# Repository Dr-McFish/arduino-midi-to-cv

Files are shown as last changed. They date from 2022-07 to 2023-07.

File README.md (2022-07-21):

# arduino-midi-to-cv
This arduino project accsepts MIDI input and translates it into various control voltages for a synthesiser.

## Features

 * 0 to 5 volt v/octave output, with 0V corresponding to MIDI note 36 (C2).
 * Monophonic, highest note priority
 * Gate Output
 
### Work in progress (planned features):

 * Pitch bend support (on the v/octave output)
 * Mod wheel output
 * Velocity output
 * OLED screen with options menu
 * Note priority option
 * Gate retrigger/legato option

## Installation requirements

 * if one desires this to work over usb, then flashing the [mocoLUFA](https://github.com/kuwatay/mocolufa) firware to the arduino is required. I personaly found this [tutorial](https://youtu.be/-bCz2I9SMAA) helpfull. Otherwise use a 5 pin MIDI connector circuit(not shown).
 * Upload with arduino IDE or comand line utility

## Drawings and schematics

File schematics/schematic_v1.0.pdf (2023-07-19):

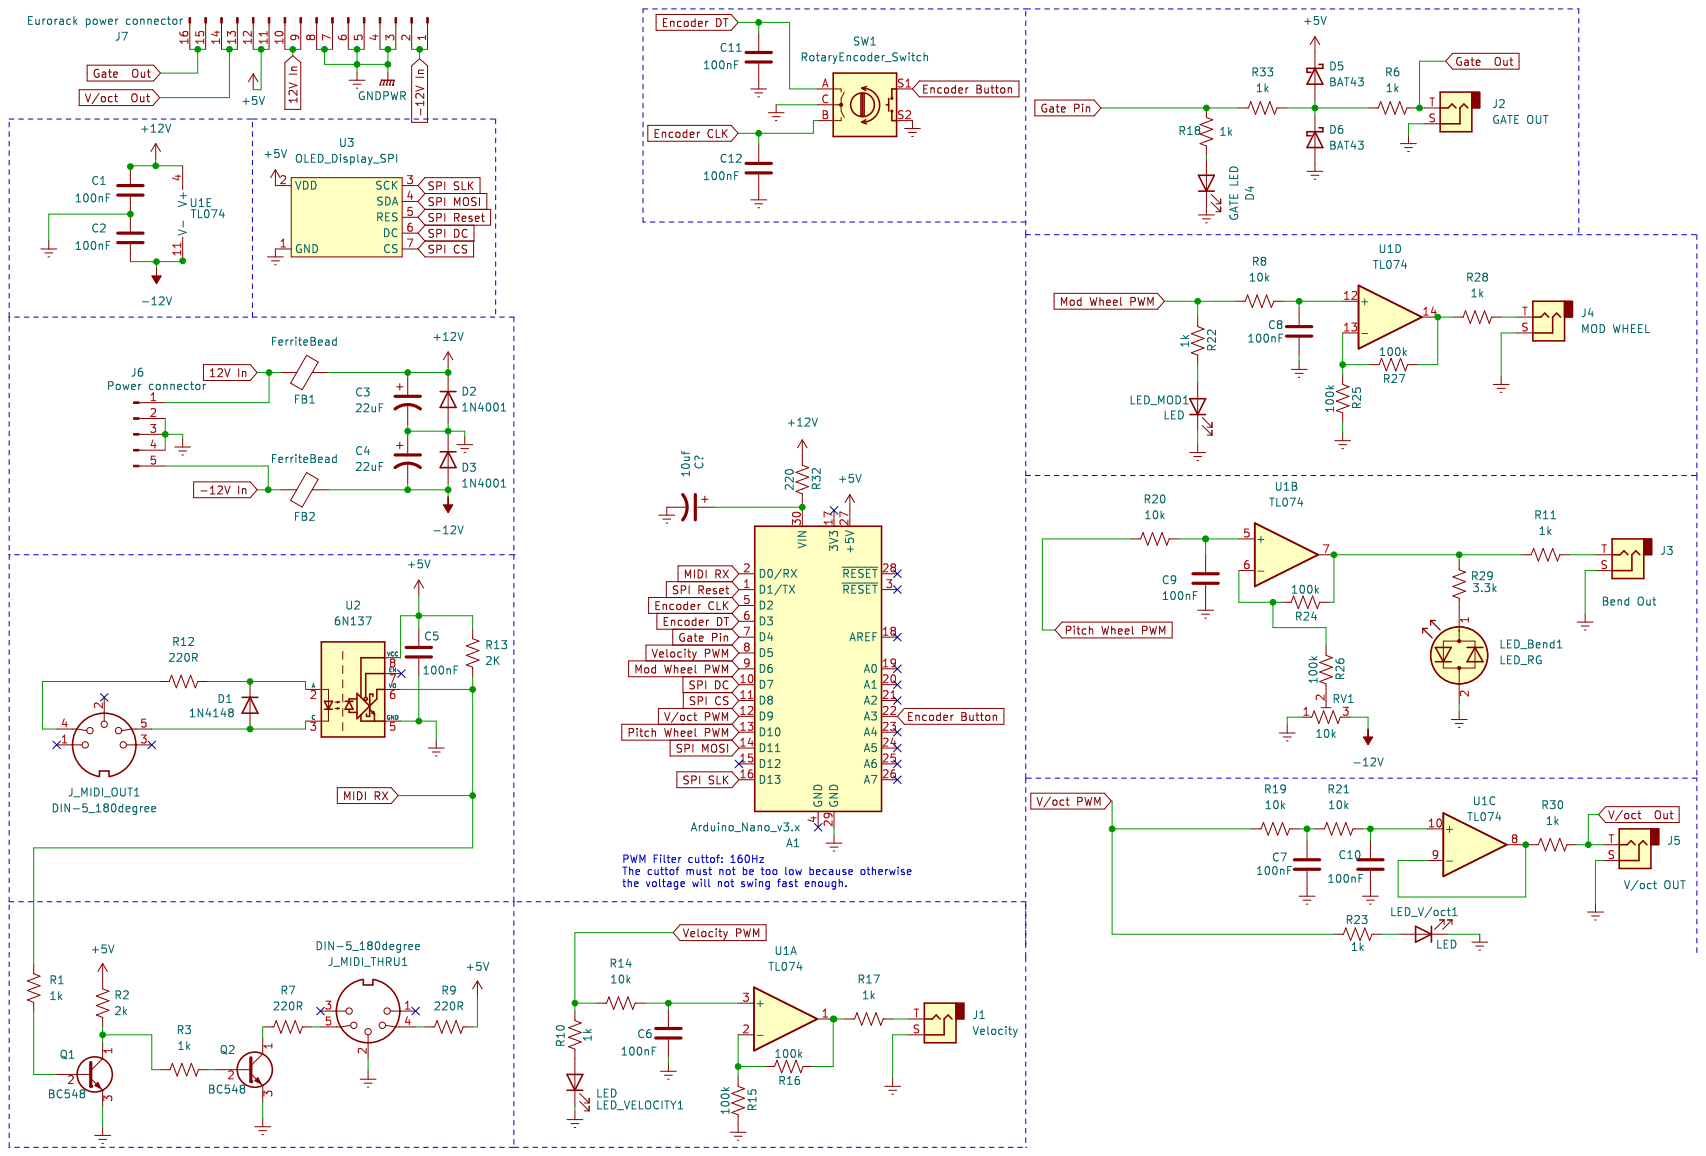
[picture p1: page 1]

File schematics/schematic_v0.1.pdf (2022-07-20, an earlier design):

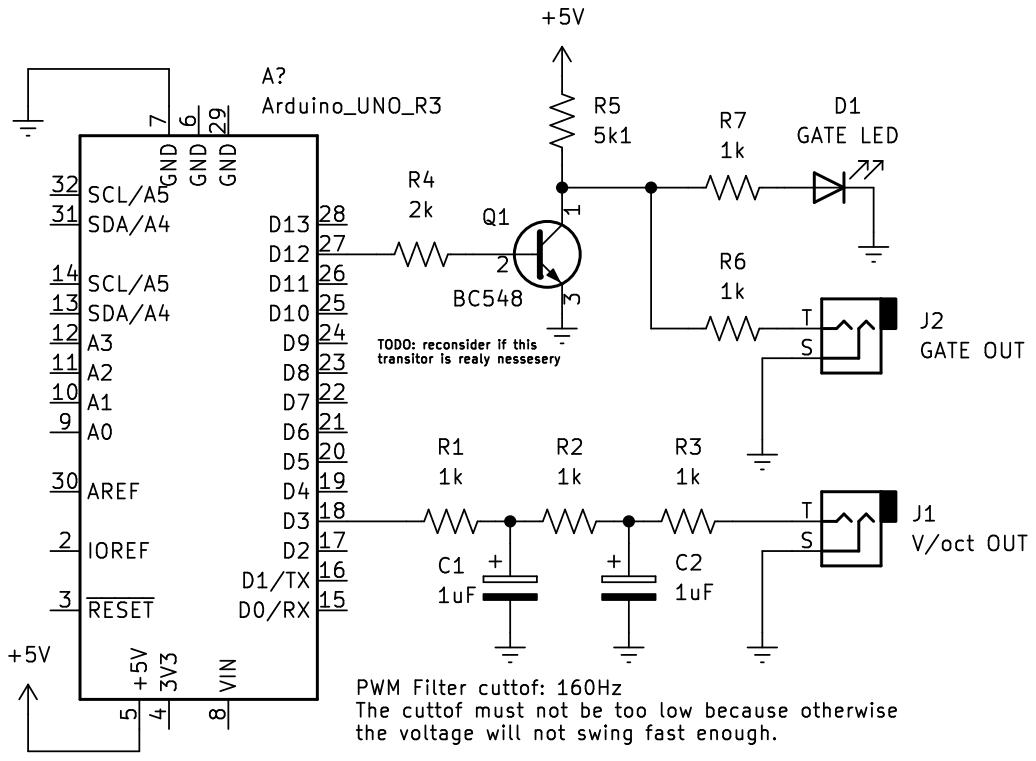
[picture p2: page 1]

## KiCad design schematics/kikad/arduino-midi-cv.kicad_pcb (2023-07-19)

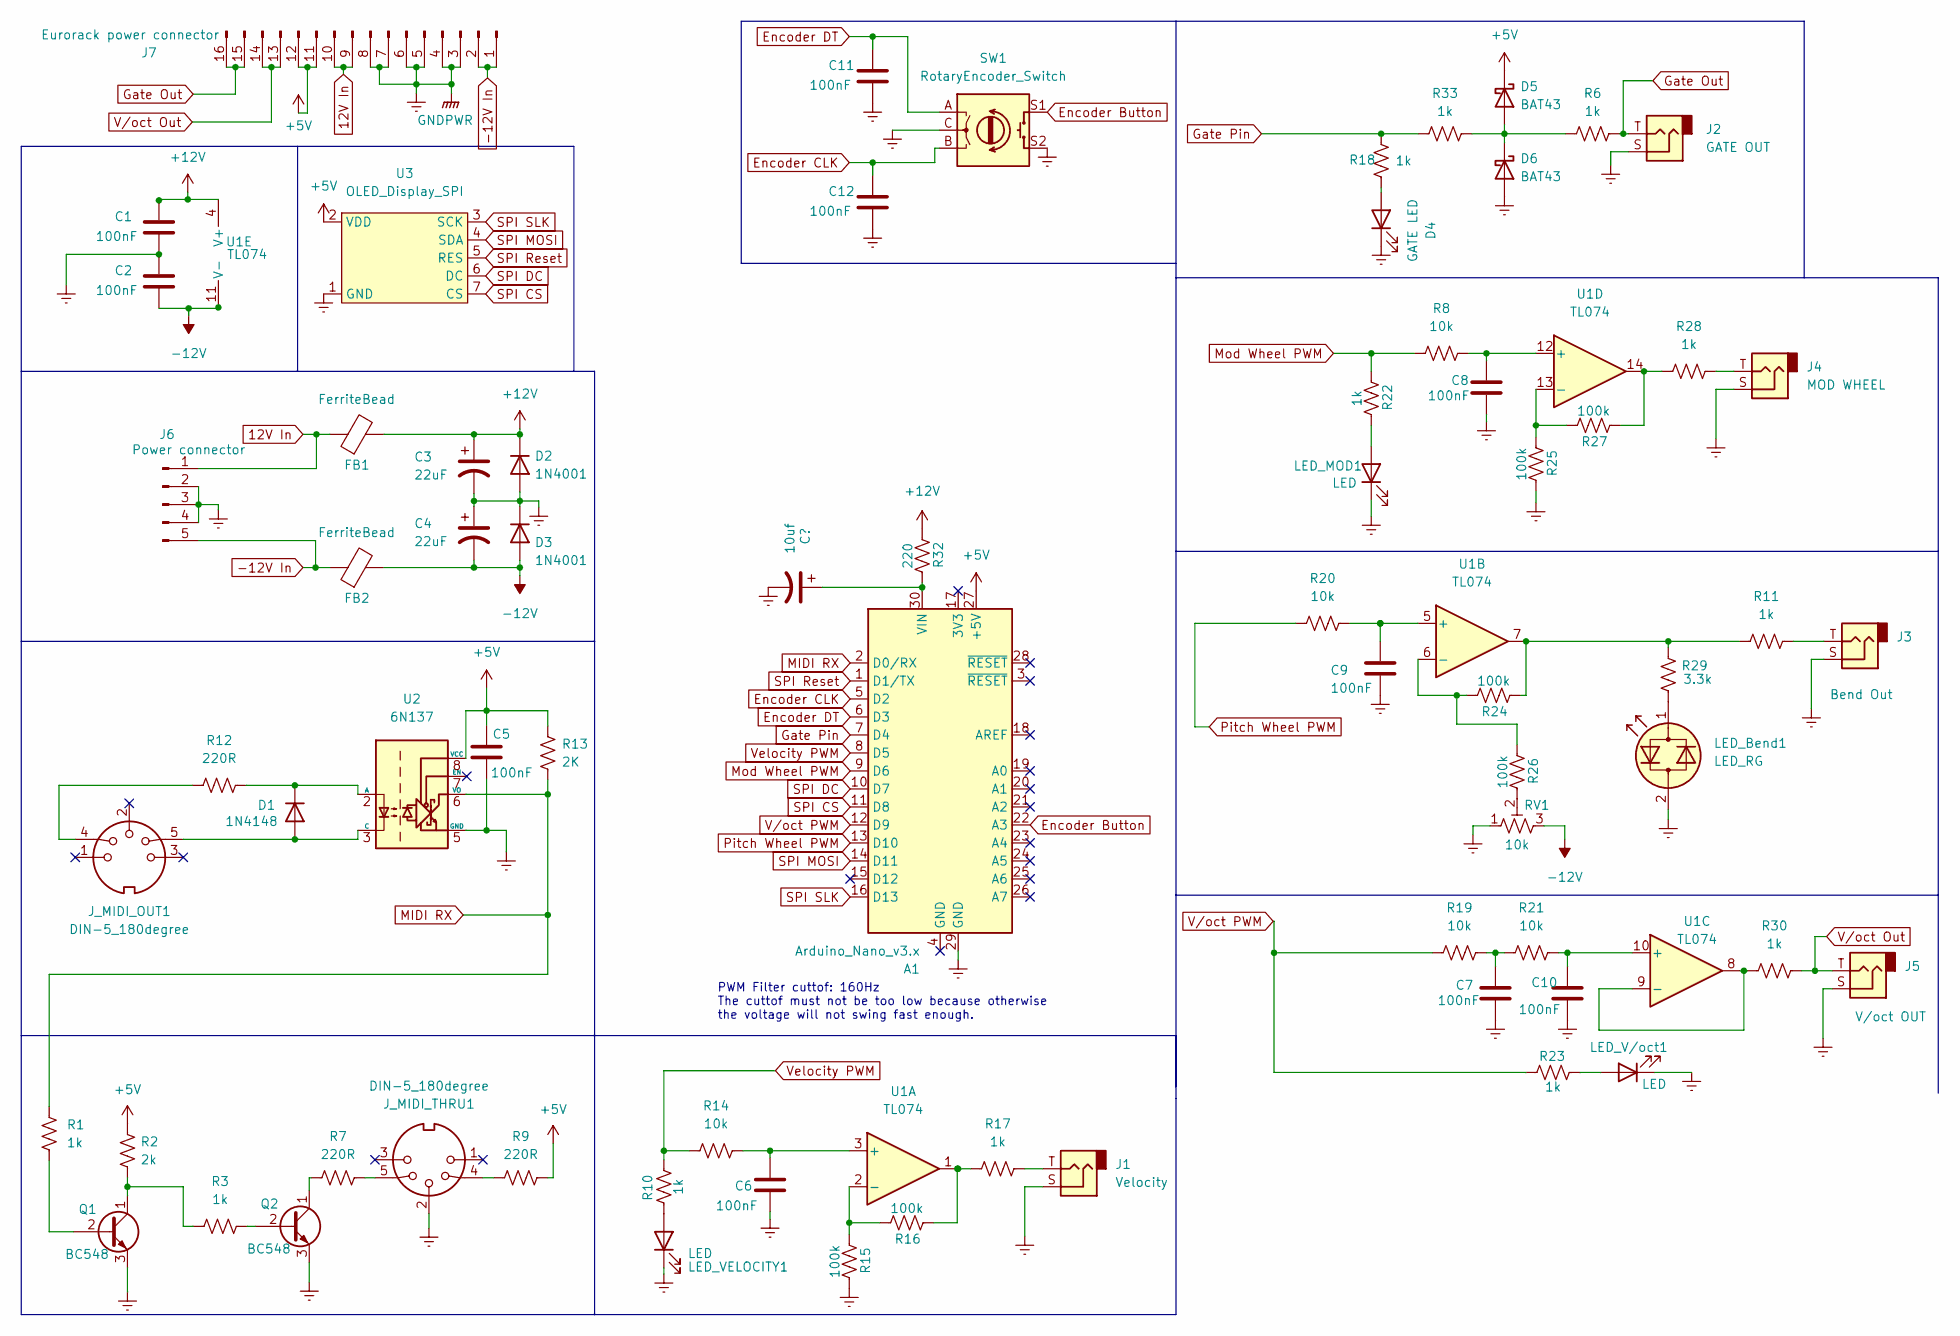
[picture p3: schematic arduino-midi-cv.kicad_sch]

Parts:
A1: Arduino_Nano_v3.x; Arduino_Nano
C1, C2, C5, C6, C7, C8, C9, C10, C11, C12: 100nF; C_Disc_D3.0mm_W1.6mm_P2.50mm
C3, C4: 22uF; CP_Radial_D5.0mm_P2.50mm
D1: 1N4148; D_DO-35_SOD27_P2.54mm_Vertical_AnodeUp
D2, D3: 1N4001; D_DO-41_SOD81_P12.70mm_Horizontal
D4: GATE LED; LED_D5.0mm
D5, D6: BAT43; D_DO-35_SOD27_P7.62mm_Horizontal
FB1, FB2: FerriteBead; R_Axial_DIN0207_L6.3mm_D2.5mm_P10.16mm_Horizontal
J1: Velocity; Jack breakcout cables
J2: GATE OUT; Jack breakcout cables
J3: Bend Out; Jack breakcout cables
J4: MOD WHEEL; Jack breakcout cables
J5: V/oct OUT; Jack breakcout cables
J6: Power connector; JST_XH_B5B-XH-A_1x05_P2.50mm_Vertical
J7: Eurorack power connector; IDC-Header_2x08_P2.54mm_Vertical
J_MIDI_OUT1: DIN-5_180degree; SIP-2
J_MIDI_THRU1: DIN-5_180degree; SIP-2
LED_Bend1: LED_RG; LED_D5.0mm
LED_MOD1: LED; LED_D5.0mm
LED_V/oct1: LED; LED_D5.0mm
LED_VELOCITY1: LED; LED_D5.0mm
Q1, Q2: BC548; TO-92_Inline
R1, R3, R6, R10, R11, R17, R18, R22, R23, R28, R30, R33: 1k; R_Axial_DIN0207_L6.3mm_D2.5mm_P10.16mm_Horizontal
R2: 2k; R_Axial_DIN0207_L6.3mm_D2.5mm_P10.16mm_Horizontal
R7, R9: 220R; R_Axial_DIN0207_L6.3mm_D2.5mm_P10.16mm_Horizontal
R8, R14, R19, R20, R21: 10k; R_Axial_DIN0207_L6.3mm_D2.5mm_P10.16mm_Horizontal
R12: 220R; R_Axial_DIN0207_L6.3mm_D2.5mm_P2.54mm_Vertical
R13: 2K; R_Axial_DIN0207_L6.3mm_D2.5mm_P7.62mm_Horizontal
R15, R26: 100k; R_Axial_DIN0207_L6.3mm_D2.5mm_P10.16mm_Horizontal
R16, R24, R25, R27: 100k; R_Axial_DIN0207_L6.3mm_D2.5mm_P2.54mm_Vertical
R29: 3.3k; R_Axial_DIN0207_L6.3mm_D2.5mm_P10.16mm_Horizontal
R32: 220; R_0805_2012Metric_Pad1.20x1.40mm_HandSolder
RV1: 10k; Potentiometer_Bourns_3296W_Vertical
SW1: RotaryEncoder_Switch; RotaryEncoder_Alps_EC11E-Switch_Vertical_H20mm
U1: TL074; DIP-14_W7.62mm_Socket
U2: 6N137; DIP-8_W7.62mm
U3: OLED_Display_SPI; SPI Oled dislay SH1106

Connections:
12V In: FB1.1, J6.1, J7.9, J7.10
+5V: A1.27 (+5V), C5.1, D5.1 (K), J7.11, J7.12, R2.2, R9.1, R13.2, U2.8 (VCC), U3.2 (VDD)
+12V: C1.1, C3.1, D2.1 (K), FB1.2, R32.2, U1.4 (V+)
-12V: C2.2, C4.2, D3.2 (A), FB2.2, RV1.3, U1.11 (V-)
-12V In: FB2.1, J6.5, J7.1, J7.2
Earth: A1.29 (GND), C1.2, C2.1, C3.2, C4.1, C5.2, C6.2, C7.2, C8.2, C9.2, C10.2, C11.2, C12.2, D2.2 (A), D3.1 (K), D4.1 (K), D6.2 (A), J1.S, J2.S, J3.S, J4.S, J5.S, J6.2, J6.3, J6.4, J7.3, J7.4, J7.5, J7.6, J7.7, J7.8, J_MIDI_THRU1.2, LED_Bend1.2 (AK), LED_MOD1.1 (K), LED_V/oct1.1 (K), LED_VELOCITY1.1 (K), Q1.3 (E), Q2.3 (E), R15.1, R25.1, RV1.1, SW1.C, SW1.S2, U2.5 (GND), U3.1 (GND)
Encoder Button: A1.22 (A3), SW1.S1
Encoder CLK: A1.5 (D2), C12.1, SW1.B
Encoder DT: A1.6 (D3), C11.1, SW1.A
Gate Out: J2.T, J7.15, J7.16, R6.2
Gate Pin: A1.7 (D4), R18.1, R33.1
MIDI RX: A1.2 (D0/RX), R1.2, R13.1, U2.6 (VO)
Mod Wheel PWM: A1.9 (D6), R8.1, R22.2
unnamed: A1.30 (VIN), R32.1
unnamed: C6.1, R14.2, U1.3 (+)
unnamed: C7.1, R19.2, R21.1
unnamed: C8.1, R8.2, U1.12 (+)
unnamed: C9.1, R20.2, U1.5 (+)
unnamed: C10.1, R21.2, U1.10 (+)
unnamed: D1.1 (K), R12.2, U2.2 (A)
unnamed: D1.2 (A), J_MIDI_OUT1.5, U2.3 (C)
unnamed: D4.2 (A), R18.2
unnamed: D5.2 (A), D6.1 (K), R6.1, R33.2
unnamed: J1.T, R17.2
unnamed: J3.T, R11.2
unnamed: J4.T, R28.2
unnamed: J_MIDI_OUT1.4, R12.1
unnamed: J_MIDI_THRU1.4, R9.2
unnamed: J_MIDI_THRU1.5, R7.1
unnamed: LED_Bend1.1 (KA), R29.2
unnamed: LED_MOD1.2 (A), R22.1
unnamed: LED_V/oct1.2 (A), R23.1
unnamed: LED_VELOCITY1.2 (A), R10.2
unnamed: Q1.1 (C), R2.1, R3.2
unnamed: Q1.2 (B), R1.1
unnamed: Q2.1 (C), R7.2
unnamed: Q2.2 (B), R3.1
unnamed: R11.1, R24.2, R29.1, U1.7
unnamed: R15.2, R16.1, U1.2 (-)
unnamed: R16.2, R17.1, U1.1
unnamed: R24.1, R26.2, U1.6 (-)
unnamed: R25.2, R27.1, U1.13 (-)
unnamed: R26.1, RV1.2
unnamed: R27.2, R28.1, U1.14
unnamed: R30.1, U1.8, U1.9 (-)
Pitch Wheel PWM: A1.13 (D10), R20.1
SPI CS: A1.11 (D8), U3.7 (CS)
SPI DC: A1.10 (D7), U3.6 (DC)
SPI MOSI: A1.14 (D11), U3.4 (SDA)
SPI Reset: A1.1 (D1/TX), U3.5 (RES)
SPI SLK: A1.16 (D13), U3.3 (SCK)
Velocity PWM: A1.8 (D5), R10.1, R14.1
V/oct Out: J5.T, J7.13, J7.14, R30.2
V/oct PWM: A1.12 (D9), R19.1, R23.2

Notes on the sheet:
PWM Filter cuttof: 160Hz The cuttof must not be too low because otherwise the voltage will not swing fast enough.

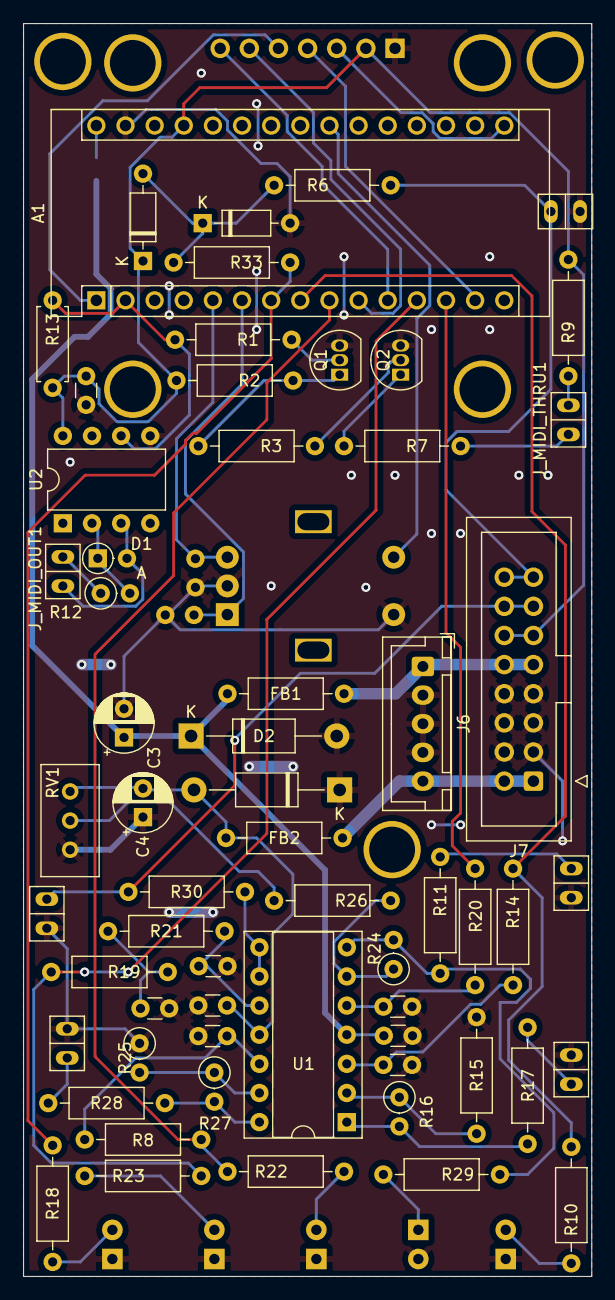
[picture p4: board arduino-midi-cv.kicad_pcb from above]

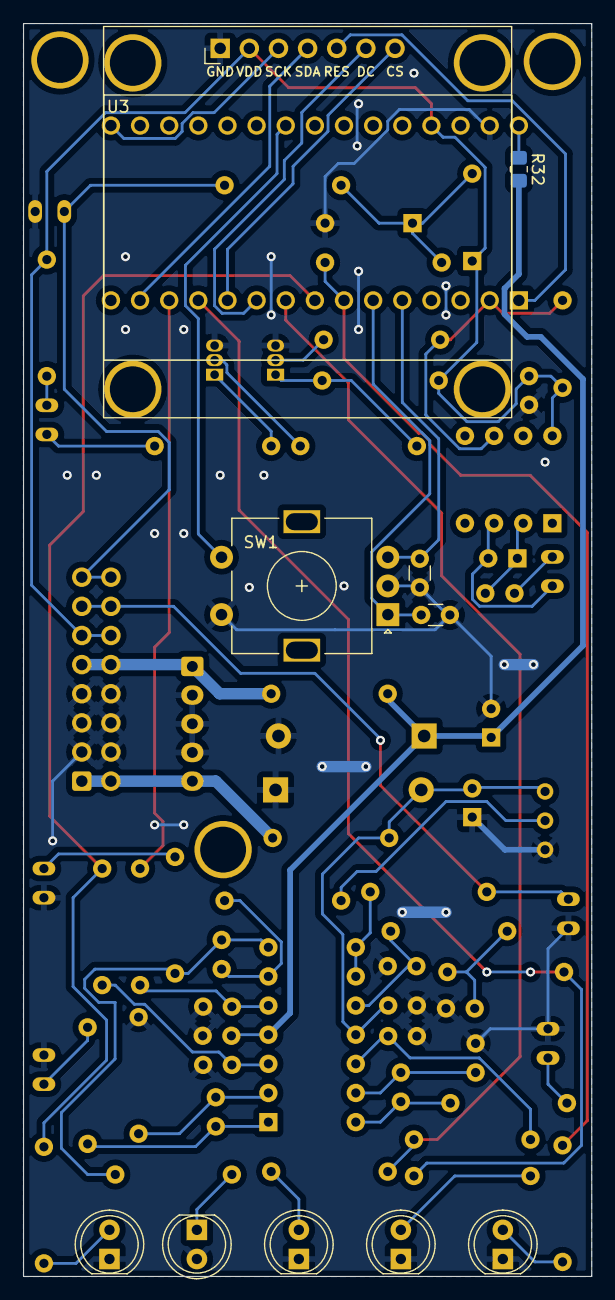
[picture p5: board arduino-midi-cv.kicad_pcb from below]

Board: 2 copper layers, 49.5 x 109.2 mm, 71 parts (10 on the bottom side), 54 nets.

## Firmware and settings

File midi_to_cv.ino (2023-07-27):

#include <MCP_DAC.h>
#include <MIDI.h>
#include <stdint.h>

#include "encoder.h"
#include "display.h"
#include "bool_array.hpp"
#include "settings.h"

constexpr int8_t MIN_NOTE =36; /*note C2*/
constexpr int8_t NUM_OCTAVES = 8;
typedef int note_number_t; /* 0 - 60; MIN_NOTE is 0 */

int pitchbend = 0;

BoolArray notes_on = BoolArray();
bool note_on_update = false;
MIDI_CREATE_DEFAULT_INSTANCE();

const int gate_pin = 4; // D4 -> pin PD4 on Atmega328p
const int gate_pin_bitmask = 4; // bit 4 on the `PORTD` register
const int enc_btn_pin = A3;
const int enc_btn_pin_bitmask = 3; //bit 3 on the `PORTC` register

int note_to_volt_per_oct_10bit(byte note);
note_number_t midinote_to_notenum(byte midi_note);

void HandleNoteOn(byte channel, byte pitch, byte velocity);
void HandleNoteOff(byte channel, byte pitch, byte velocity) ;
void HandleCC(byte channel, byte control_function, byte parameter);
void HandlePitchBend(byte channel, int bend);

inline void updateNoteAndGate();
inline void updateMenu();

MCP4922 MCP;  // HW SPI DAC
enum DAC_CHANNEL {
	CH_V_OCT = 0, //Channel A
	CH_PITCH_BEND = 1, //Channel B
};

struct settings_s settings = {{4, 12}, 0b00000100, 0, false};


void setup() 
{
	// ------------------------------------------------- MIDI -------------------------------------------------- 
	MIDI.begin(MIDI_CHANNEL_OMNI);
	MIDI.turnThruOff();
	//Serial.begin(9600);
	
	// As of the MIDI Library v3.1, the lib uses C style function 
	// pointers to create a callback system for handling input events. 
	MIDI.setHandleNoteOn(HandleNoteOn); 
	MIDI.setHandleControlChange(HandleCC);
	MIDI.setHandleNoteOff(HandleNoteOff);
	MIDI.setHandlePitchBend(HandlePitchBend);

	// ------------------------------------------------ display ------------------------------------------------
	display_setup();
	draw_text("hello");
	// ------------------------------------------------ encoder ------------------------------------------------ 
	setup_encoder();
	
	// -------------------------------------------------- DAC --------------------------------------------------
	// Todo: it may be fasater to use SPI library insted of this MCP library
	MCP.begin(A4);
	MCP.setGain(2);


	// ----------------------------------------------- Gate pin ------------------------------------------------  

	pinMode(gate_pin, OUTPUT);
	pinMode(A3, INPUT_PULLUP);


	// TODO : migrate mod and velocity to Timer 1(pins 9 and 10) for more resolution(and less scary high frequencies? I have no idea what I am doing)

	// ###################################### DEPRICATED! Replaced with DAC! ######################################

	// pinMode(9, OUTPUT); // Volt per octave
	// pinMode(10, OUTPUT); // Pitch Wheel raw
	// ------------------------------------------------ TIMER 1 ------------------------------------------------
	// //       Enable PWM out on pin D9(OC1A)    Enable PWM out on pin D10(OC1B)      Fast PWM 10bit mode
	// TCCR1A = _BV(COM1A1)                     | _BV(COM1B1)                        | _BV(WGM11) | _BV(WGM10); //WGM12
	// //        prescaler of 1, 15,6kHz
	// TCCR1B = _BV(CS10)                                                            | _BV(WGM12);
	// OCR1A = 0; // pin D9  pwm value (0-1023) (v/oct)
	// OCR1B = 0x01Ff; // pin D10 pwm value (0-1023) (pitchbend)
	write_bend(0);

	pinMode(6, OUTPUT); // Mod Wheel
	pinMode(5, OUTPUT); // Velocity
	// ------------------------------------------------ TIMER 0 ------------------------------------------------
	//        Enable PWM pin D6              Enable PWM pin D5                Fast PWM mode
	//        Clear OC0A on compare match    Clear OC0B on compare match      TOP = 0xFF;
	//        set OC0A at BOTTOM             set OC2B at BOTTOM,              Update of OCRx at BOTTOM
	TCCR0A = _BV(COM0A1)                   | _BV(COM0B1)                     | _BV(WGM01) | _BV(WGM00);
	//        PRESCALER is set to 1 (62.5 kHz sheesh), more than 20
	TCCR0B = _BV(CS00);
	OCR0A = 0; // pin D6  pwm value (0-255) (Mod Wheel)
	OCR0B = 0; // pin D5  pwm value (0-255) (velocity)
}

int16_t note_to_volt_per_oct_12bit(byte note){
	// because of the 4 x 2.048V voltage refference, the value writen to the DAC is in 2 milivolts
	// (int)1 <=> 2 mV
	const int16_t note_range_limited = max(0, min((int16_t)(note) - MIN_NOTE, 12 * NUM_OCTAVES)); // range of 4 octaves
	Serial.print("note #");
	Serial.print(note_range_limited);
	Serial.print("  |  ");
	Serial.print((note_range_limited * (int16_t)500) / (int16_t)12);
	Serial.println("mV");
	return (note_range_limited * (int16_t)500) / (int16_t)12;
}


inline void write_v_oct(byte note_num) {
	MCP.analogWrite(note_to_volt_per_oct_12bit(note_num), DAC_CHANNEL::CH_V_OCT);
}
/* bend is the MIDI bend value, so 14 bits */
inline void write_bend(int16_t bend) {
	//Serial.println((bend - MIDI_PITCHBEND_MIN) / 4);
	MCP.analogWrite( ( MIDI_PITCHBEND_MAX - bend ) / 4, DAC_CHANNEL::CH_PITCH_BEND);
}

inline void write_mod(uint8_t val) {
	OCR0A = val;
}
inline void write_velocity(uint8_t val) {
	OCR0B = val;
}


void loop() {
	MIDI.read();

	updateNoteAndGate();
	updateMenu();
}

// Loop subrutines
inline void updateNoteAndGate() {
	if (note_on_update) {
		note_on_update = false;
		int prioritized_note;
		if(settings.flags & _BV(NOTE_PRIORITY)){
			//HIGHEST:
			prioritized_note = notes_on.highest();
		} else {
			//LOWEST:
			prioritized_note = notes_on.lowest();
		}

		if (prioritized_note == -1) {
			PORTD &= ~_BV(gate_pin_bitmask);
		} else {
			PORTD |= _BV(gate_pin_bitmask);
		
			//sets PWM on v/oct pin to the appropriate note
			write_v_oct(prioritized_note);
			// TODO (maybe) software pitch bend settings.nums[PITCH_BEND]) if the circuit version is insuficient
		}
	}
}

inline void updateMenu() {
	// encoder rotation
	int encoder_dir;
	switch(encoder_get()){
		case CW_ST:
		encoder_dir = -1;
		break;
		case NEUTRAL_ST:
		encoder_dir = 0;
		break;
		case CCW_ST:
		encoder_dir = 1;
		break;
	}

	// encoder_button
	static bool last_button = false;
	static int debounce_time = 0;
	
	bool button = ((~PINC) & _BV(enc_btn_pin_bitmask));
	bool rising_edge = (!last_button) && button;
	bool button_press;
	last_button = button;
	
	if(rising_edge) {
		if(debounce_time == 0) {
			debounce_time = 8000; // TODO ajust
			button_press = true;
		} else {
			button_press = false;
			debounce_time += 2000;
		}
	}

	if(encoder_dir || button_press){
		edit_settings(encoder_dir, button_press, &settings);
		display_options(&settings);
	}

	if(debounce_time > 0)
		debounce_time--;
}

//------------------------------------------------------------------------------------------------------------------------------------------
//
// MIDI callbacks


void HandleNoteOn(byte channel, byte pitch, byte velocity) 
{
	if(settings.nums[MIDI_CHANNEL] == channel) {
		notes_on.setb(pitch);

		//(velocity)
		OCR0B = velocity * 2;  

	}
	note_on_update = true;
	Serial.print("Recive note: ");
	Serial.println(pitch);
}

void HandleNoteOff(byte channel, byte pitch, byte velocity) 
{
	if(settings.nums[MIDI_CHANNEL] == channel) {
		notes_on.clearb(pitch);

		if(settings.flags & _BV(NOTEOFF_VEL))
		OCR0B = velocity;
	}
	note_on_update = true;
}

void HandleCC(byte channel, byte control_function, byte parameter)
{
	if(settings.nums[MIDI_CHANNEL] == channel) {
		switch(control_function) {
		  default:
			break;
		  case midi::ModulationWheel : //MSB
			OCR0A = ((uint8_t)parameter) * 2;
			break;
		  case midi::ModulationWheel + 32 : //LSB
			OCR0A &= 0x11111110;
			OCR0A |= parameter >> 6;
			break;
		  case midi::AllNotesOff :
			PORTD |= _BV(gate_pin_bitmask); // set gate pin low
			notes_on.clear_all();
			note_on_update = true;
			break;
		}
	}
}

void HandlePitchBend(byte channel, int bend) {
	if(settings.nums[MIDI_CHANNEL] == channel){
		pitchbend = bend;
		write_bend(bend);
	}
}

//------------------------------------------------------------------------------------------------------------------------------------------
//
// functions

int note_to_volt_per_oct_10bit(byte note){
	int16_t pitch = note;
	pitch *= 341;
	pitch = (pitch / 20) + ((pitch % 20) >= 10 ? 1 : 0);
	return pitch;
}

note_number_t midinote_to_notenum(byte midi_note) {
	int min_note = MIN_NOTE;
	int max_note = MIN_NOTE  + (12*5);
	if (settings.flags & _BV(BEND_GUARDS)) {
		min_note += settings.nums[PITCH_BEND];
		max_note -= settings.nums[PITCH_BEND];
	}
		
	return max(min_note, min(max_note, midi_note)) - min_note;
}

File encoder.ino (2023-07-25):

/*******Interrupt-based Rotary Encoder Sketch*******
by Simon Merrett, based on insight from Oleg Mazurov, Nick Gammon, rt, Steve Spence
https://www.instructables.com/Improved-Arduino-Rotary-Encoder-Reading/
modified a litle bit by Dr_McFish
*/
#include "encoder.h"

volatile byte aFlag = 0; // let's us know when we're expecting a rising edge on ENCODER_PIN_A to signal that the encoder has arrived at a detent
volatile byte bFlag = 0; // let's us know when we're expecting a rising edge on ENCODER_PIN_B to signal that the encoder has arrived at a detent (opposite direction to when aFlag is set)
volatile byte reading = 0; //somewhere to store the direct values we read from our interrupt pins before checking to see if we have moved a whole detent

volatile enum ENCODER_STATE encoder_state = NEUTRAL_ST;

void setup_encoder() {
	pinMode(ENCODER_PIN_A, INPUT_PULLUP); // set ENCODER_PIN_A as an input, pulled HIGH to the logic voltage (5V or 3.3V for most cases)
	pinMode(ENCODER_PIN_B, INPUT_PULLUP); // set ENCODER_PIN_B as an input, pulled HIGH to the logic voltage (5V or 3.3V for most cases)
	attachInterrupt(0,PinA,RISING); // set an interrupt on PinA, looking for a rising edge signal and executing the "PinA" Interrupt Service Routine (below)
	attachInterrupt(1,PinB,RISING); // set an interrupt on PinB, looking for a rising edge signal and executing the "PinB" Interrupt Service Routine (below)
}

void PinA(){
	cli(); //stop interrupts happening before we read pin values
	reading = PIND & 0xC; // read all eight pin values then strip away all but ENCODER_PIN_A and ENCODER_PIN_B's values
	if(reading == B00001100 && aFlag) { //check that we have both pins at detent (HIGH) and that we are expecting detent on this pin's rising edge
		encoder_state = CCW_ST;
		bFlag = 0; //reset flags for the next turn
		aFlag = 0; //reset flags for the next turn
	}
	else if (reading == B00000100) bFlag = 1; //signal that we're expecting ENCODER_PIN_B to signal the transition to detent from free rotation
	sei(); //restart interrupts
}

void PinB(){
	cli(); //stop interrupts happening before we read pin values
	reading = PIND & 0xC; //read all eight pin values then strip away all but ENCODER_PIN_A and ENCODER_PIN_B's values
	if (reading == B00001100 && bFlag) { //check that we have both pins at detent (HIGH) and that we are expecting detent on this pin's rising edge
		encoder_state = CW_ST;
		bFlag = 0; //reset flags for the next turn
		aFlag = 0; //reset flags for the next turn
	}
	else if (reading == B00001000) aFlag = 1; //signal that we're expecting ENCODER_PIN_A to signal the transition to detent from free rotation
	sei(); //restart interrupts
}

enum ENCODER_STATE encoder_get() {
	cli();
	if (encoder_state != NEUTRAL_ST) {
		enum ENCODER_STATE temp = encoder_state;
		encoder_state = NEUTRAL_ST;
		sei();
		return temp;
	} else {
		sei();
		return encoder_state;
	}
}

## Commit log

2022-07-20 Add basic noteOn and noteOff support. PROTOTYPE
2022-07-20 add kikad schematic
    [arduino-midi-cv.kicad_pcb, arduino-midi-cv.kicad_sch]
2022-07-21 Fix schematic pdf
2022-07-21 Upgrade v/oct to the 10 bit timer
2022-07-21 Add velocity support, add mod wheel support,
2022-08-24 Update schematics
    [arduino-midi-cv.kicad_sch]
2022-08-25 Redraw schematics to be more butiful
    [arduino-midi-cv.kicad_sch]
2022-08-25 Add midi CC defines Add Pitch bend PWM on pin D9 Replace digitalWrite() with port manipulation for speed
    [midi_to_cv.ino]
2022-08-28 Start PCB
    [arduino-midi-cv.kicad_pcb, arduino-midi-cv.kicad_sch]
2022-08-29 Add encoder
2022-08-30 Add Bool Array and Fix Bool Array
    [midi_to_cv.ino]
2022-08-31 Add settings menue ui prototype
2022-08-31 Add working menue first page prototype this code is to be reworked to make it more scalable and less terrible basicly
    [display.ino, encoder.ino, midi_to_cv.ino]
2022-10-28 Add encoder button debounce
2023-07-19 There has been some work done, a long time a go I have no idea what
    [BUSSBOARD.kicad_pcb, BUSSBOARD.kicad_sch, arduino-midi-cv.kicad_pcb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]
2023-07-20 Add DAC to shematic (untested)
    [arduino-midi-cv.kicad_sch]
2023-07-25 Change indentation to tabs. To HELL with spaces!
    [arduino-midi-cv.kicad_sch]
2023-07-27 Note priory fixes and general refactoring
    [arduino-midi-cv.kicad_sch]
2023-07-27 update schematic with new design
    [arduino-midi-cv.kicad_sch]
